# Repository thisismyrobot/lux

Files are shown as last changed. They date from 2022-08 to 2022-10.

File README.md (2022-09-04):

# Lux

A custom lux meter.

## Hardware

 - ESP-12F ESP8266 (bare)
 - BH1750 Ambient Light Sensor
 - Geekcreit 0.91 128x32 I2C OLED display
 - Resistors etc to support bare ESP8266
 - USB -> TTL (3.3v) adaptor for programming
 - Exact power supply TBD

## Enclosure

Laser-cut plates added to an purchased enclosure.

[Outlines DXF](https://github.com/thisismyrobot/lux/raw/main/hardware/2d_plates.dxf)

[Preview assembled](hardware/model.stl)

### Mock-up

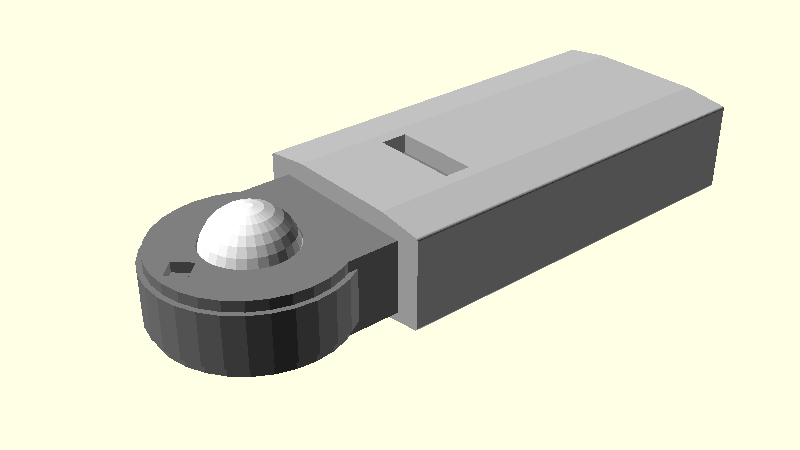
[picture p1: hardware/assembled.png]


### Plates

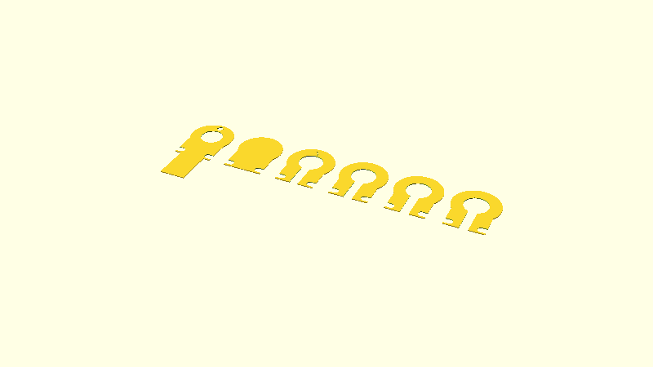
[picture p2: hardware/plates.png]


## Hat tips

https://www.instructables.com/ESP8266-Pro-Tips/

https://www.instructables.com/ESP-12F-ESP8266-Module-Minimal-Breadboard-for-Flas/

https://randomnerdtutorials.com/esp8266-nodemcu-bh1750-ambient-light-sensor/

https://learn.sparkfun.com/tutorials/esp8266-thing-hookup-guide/using-the-arduino-addon

https://randomnerdtutorials.com/esp8266-pinout-reference-gpios/

https://randomnerdtutorials.com/esp8266-0-96-inch-oled-display-with-arduino-ide/

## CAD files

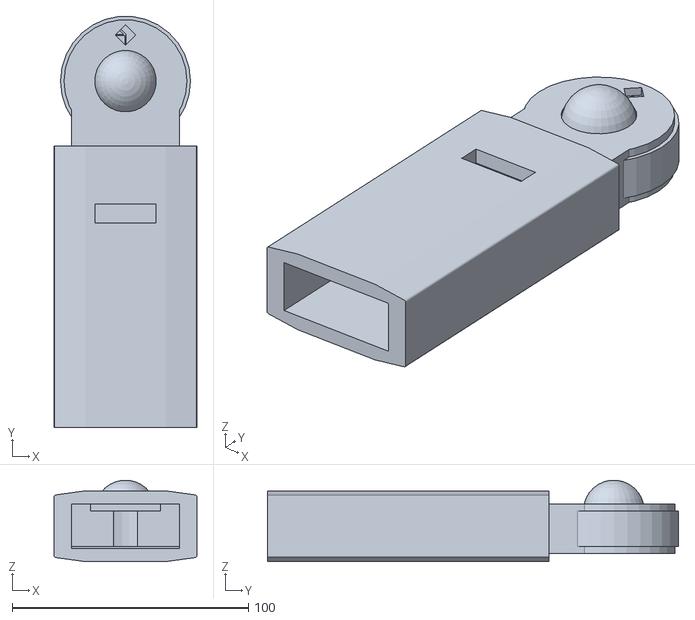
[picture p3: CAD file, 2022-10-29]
hardware/model.stl
60.4 x 173.8 x 34.4

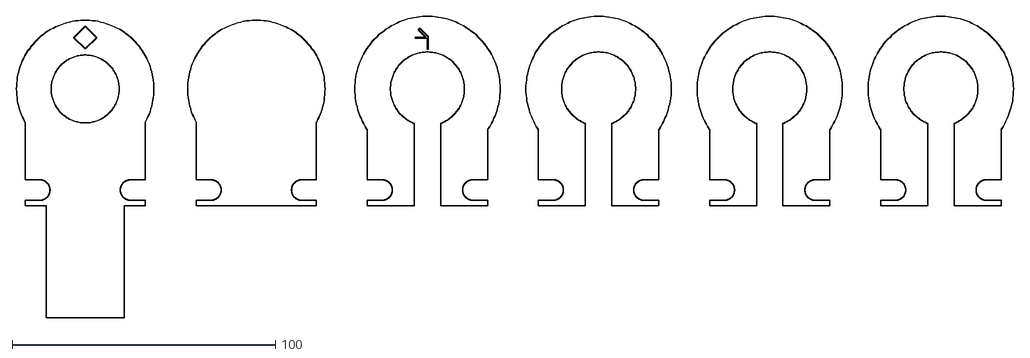
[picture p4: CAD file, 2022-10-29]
hardware/2d_plates.dxf
378.7 x 114.5

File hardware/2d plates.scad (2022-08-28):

$fn = 100;

case_width = 55;
case_radius = 5;

upper_dome_diam = 25.8;
lower_dome_diam = 28;
upper_dome_offset = 7;

upper_display_length = 23;
upper_display_width = 6;
upper_display_offset = 17;
lower_display_width = 12;
lower_display_length = 38.2;
lower_display_length_offset = 6.7;  // Pins end.

module plate() {
    offset(r=case_radius) square(case_width-case_radius*2, center=true);
}

module upper_plate() {
    difference() {
        plate();
        translate([0, upper_dome_offset, 0]) {
            circle(d=upper_dome_diam);
        }
        translate([0, -upper_display_offset, 0]) {
            square([upper_display_length, upper_display_width], center=true);
        }
    }
}

module lower_plate() {
    difference() {
        plate();
        translate([0, upper_dome_offset, 0]) {
            circle(d=lower_dome_diam);
        }
        cutout_offset = ((lower_display_length - upper_display_length) / 2) - lower_display_length_offset;
        echo(cutout_offset);

        translate([cutout_offset, -upper_display_offset, 0]) {
            square([lower_display_length, lower_display_width], center=true);
        }
    }
}

upper_plate();
translate([case_width+10, 0, 0]) lower_plate();

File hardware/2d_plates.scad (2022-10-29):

mode = "";
export = mode == "export";
$fn = export ? 150 : 30;

kerf = export ? 0.2 : 0;  // mm diameter of laser beam

plate_width = 55;
plate_thickness = 3;
plate_offset = plate_width / 2;
plate_step = 3;

upper_dome_diam = 26;
lower_dome_diam = 28.1;
dome_inner_width = 10;

box_width = 60.4;
box_length = 119;
box_height = 30;
box_hole_width = 45.5;
box_hole_height = 19;
box_inset_length = 16.9;
box_post_width = 8;
box_post_spacing = 34.5; // centres
box_post_inset = 10.9; // centres
box_ridge_width = 35;
box_ridge_roll = 1.5;
box_ridge_drop = 2.5;

middle_plates = floor(box_hole_height / plate_thickness) - 2;
add_fill_plate = (middle_plates + 2) * plate_thickness  != box_hole_height;

box_display_slot_from_end = 24.5;
box_display_slot_height = 8;
box_display_slot_length = 25.9;

module plate(step=0,tongue=0,trim=0) {
    tongue = trim > 0 ? -trim : tongue;
    difference() {
        union() {
            circle(d=plate_width-step+kerf);
            translate([-box_hole_width/2-kerf/2, -plate_width/2-box_inset_length+trim, 0]) square([box_hole_width+kerf, box_inset_length + plate_width/2 - trim]);
            translate([-box_hole_width/2+box_post_width-kerf/2, -plate_width/2-box_inset_length-tongue, 0]) square([box_hole_width-(box_post_width*2)+kerf, box_inset_length + plate_width/2 + tongue]);
        }
        hull() {
            translate([-box_post_spacing/2, -box_post_inset-plate_width/2, 0]) circle(d=box_post_width-kerf);
            translate([-box_post_spacing, -box_post_inset-plate_width/2, 0]) circle(d=box_post_width-kerf);
        }
        hull() {
            translate([box_post_spacing/2, -box_post_inset-plate_width/2, 0]) circle(d=box_post_width-kerf);
            translate([box_post_spacing, -box_post_inset-plate_width/2, 0]) circle(d=box_post_width-kerf);
        }
    }
}

module top_plate() {
    difference() {
        plate(plate_step, box_display_slot_from_end+box_display_slot_height+10);
        circle(d=upper_dome_diam-kerf);

        width = (plate_width-plate_step-upper_dome_diam) / 2;
        translate([0, upper_dome_diam/2 + width/2, 0]) rotate([0, 0, 45]) square((width/sqrt(2))/1.5, center=true);
    }
}

module middle_plate(logo=false) {
    difference() {
        plate();
        circle(d=lower_dome_diam);
        translate([-dome_inner_width/2, -box_inset_length-plate_width/2-1, 0]) {
            square([dome_inner_width, box_inset_length+plate_width/2]);
        }
        
        if (logo) {
            width = (plate_width-plate_step-upper_dome_diam) / 2;
            translate([0, upper_dome_diam/2 + width/2, 0]) {
                rotate([0, 0, 45]) translate([-width/40, 0, 0]) square([width/20, (width/sqrt(2))/2]);
                rotate([0, 0, 90]) translate([-width/80, 0, 0]) square([width/40, (width/sqrt(2))/2]);
                rotate([0, 0, 180]) translate([-width/60, -width/60, 0]) square([width/40, (width/sqrt(2))/2]);
            }
        }
    }
}

module bottom_plate(add_fill_plate) {
    plate(plate_step, 0, add_fill_plate ? box_inset_length : 0);
}

module dome() {
    color("white") difference() {
        sphere(d=upper_dome_diam);
        translate([0, 0, -plate_width/2]) cube([plate_width, plate_width, plate_width], center=true);
    }
}

module box() {
    translate([0, 0, -box_hole_height / 2]) difference() {
        // Master box
        union() {
            base_box_height = box_height-(box_ridge_drop*2);
            translate([-box_width/2, -box_length-plate_offset, -base_box_height/2]) cube([box_width, box_length, base_box_height]);

            // Top profile
            hull() {
                translate([0, -plate_offset, 0]) {
                    translate([-box_width/2+box_ridge_roll/2, 0, base_box_height/2]) rotate([90, 0, 0]) cylinder(d=box_ridge_roll, h=box_length);
                    translate([box_width/2-box_ridge_roll/2, 0, base_box_height/2]) rotate([90, 0, 0]) cylinder(d=box_ridge_roll, h=box_length);
                    translate([-box_ridge_width/2+box_ridge_roll/2, 0, base_box_height/2+box_ridge_drop-box_ridge_roll/2]) rotate([90, 0, 0]) cylinder(d=box_ridge_roll, h=box_length);
                    translate([box_ridge_width/2-box_ridge_roll/2, 0, base_box_height/2+box_ridge_drop-box_ridge_roll/2]) rotate([90, 0, 0]) cylinder(d=box_ridge_roll, h=box_length);
                }
            }   

            // Bottom profile
            hull() {
                translate([0, -plate_offset, 0]) {
                    translate([-box_width/2+box_ridge_roll/2, 0, -base_box_height/2]) rotate([90, 0, 0]) cylinder(d=box_ridge_roll, h=box_length);
                    translate([box_width/2-box_ridge_roll/2, 0, -base_box_height/2]) rotate([90, 0, 0]) cylinder(d=box_ridge_roll, h=box_length);
                    translate([-box_ridge_width/2+box_ridge_roll/2, 0, -base_box_height/2-box_ridge_drop+box_ridge_roll/2]) rotate([90, 0, 0]) cylinder(d=box_ridge_roll, h=box_length);
                    translate([box_ridge_width/2-box_ridge_roll/2, 0, -base_box_height/2-box_ridge_drop+box_ridge_roll/2]) rotate([90, 0, 0]) cylinder(d=box_ridge_roll, h=box_length);
                }
            }   
        }
        
        // End cutouts
        translate([-box_hole_width/2, -box_length-plate_offset-1, -box_hole_height/2]) cube([box_hole_width, box_length+2, box_hole_height]);

        // lcd cutout
        translate([0, -plate_offset-(box_display_slot_height/2)-box_display_slot_from_end, box_height/2]) {
            cube([box_display_slot_length, box_display_slot_height, box_height], center=true);
        }
    }
}

if (export) {
    top_plate();
    translate([plate_width+10, 0, 0]) bottom_plate();
    for (p = [0:middle_plates-1]) {
        translate([(p+2)*(plate_width+10), 0, 0]) middle_plate(p == 0);
    }
} else {
    translate([0, 0, -plate_thickness]) dome();
    color("silver") box();
    
    color("grey") translate([0, 0, -plate_thickness]) {
        linear_extrude(height=plate_thickness) top_plate();
        for (p = [1:middle_plates + (add_fill_plate ? 1 : 0)]) {
            translate([0, 0, -p*plate_thickness]) linear_extrude(height=plate_thickness) middle_plate(p == 1);
        }
        translate([0, 0, -plate_thickness*(middle_plates+1+(add_fill_plate ? 1 : 0))]) linear_extrude(height=plate_thickness) bottom_plate(add_fill_plate);
    }
}

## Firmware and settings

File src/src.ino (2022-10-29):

/* 
 *  Add board manager URL: http://arduino.esp8266.com/stable/package_esp8266com_index.json
 *  Add board via board manager: esp8266 v3.0.2
 *  Select this ESP8266 board: Generic ESP8266 Module
 *  Install Libraries:
 *      - BH1750 v1.3.0
 *      - Adafruit SSD1306 v2.5.7
*/
#include <ESP8266WiFi.h>
#include <Wire.h>
#include <BH1750.h>
#include <Adafruit_SSD1306.h>

#define SDA_PIN 4  // GPIO4/Pin 19/D2
#define SCL_PIN 5  // GPIO5/Pin 20/D1

#define SCREEN_WIDTH 128
#define SCREEN_HEIGHT 32
#define OLED_RESET -1
#define SCREEN_ADDRESS 0x3C

BH1750 lightMeter;
Adafruit_SSD1306 display(SCREEN_WIDTH, SCREEN_HEIGHT, &Wire, OLED_RESET);

void setup() {
    WiFi.mode(WIFI_OFF);
    WiFi.forceSleepBegin();
    delay(1);

    pinMode(LED_BUILTIN, OUTPUT);

    Wire.begin(SDA_PIN, SCL_PIN);
    if(!display.begin(SSD1306_SWITCHCAPVCC, SCREEN_ADDRESS)) {
        Serial.println(F("SSD1306 allocation failed"));
        for(;;); // Don't proceed, loop forever
    }
    display.setTextSize(4);
    display.setTextColor(SSD1306_WHITE);
    
    lightMeter.begin(BH1750::CONTINUOUS_HIGH_RES_MODE_2);
}

void loop() {
    digitalWrite(LED_BUILTIN, LOW);
    delay(100);

    int lux = lightMeter.readLightLevel();
    drawLux(lux);
    
    digitalWrite(LED_BUILTIN, HIGH);
    delay(100);
}

void drawLux(int lux) {
    display.clearDisplay();
    display.setCursor(0, 0);

    int leftPad = 5 - floor(log10(lux) + 1);
    for(int i=0; i<leftPad; i++) {
        display.print(" ");
    }
    
    display.print(lux);
    display.display();
}

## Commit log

2022-08-19 Fixed serial logging, wasn't working in setup
    [src.ino]
2022-08-19 Working lux reading from the sensor
2022-08-28 Trialling some plates for laser cutting
    [2d plates.dxf, 2d plates.scad]
2022-08-28 DXF exporting with flag
    [2d_plates.dxf, 2d_plates.scad]
2022-08-31 Redesigned to be part of existing enclosure
    [2d_plates.dxf, 2d_plates.scad]
2022-08-31 Exporting STL to show the concept better
    [2d_plates.scad, model.stl]
2022-08-31 Added stack of middle plates
    [2d_plates.dxf, 2d_plates.scad, model.stl]
2022-08-31 Added step option for plates
    [2d_plates.dxf, 2d_plates.scad, model.stl]
2022-09-04 Added mounting pate for LCD, slot for LCD
    [2d_plates.dxf, 2d_plates.scad, model.stl]
2022-09-04 Improved preview of box to help with design
    [2d_plates.scad, model.stl]
2022-09-11 Tweaked maths for plate count
    [2d_plates.scad, model.stl]
2022-09-11 Added a fill plate if the plates don't add up to the gap height
    [2d_plates.dxf, 2d_plates.scad, model.stl]
2022-09-11 Bugfixes to last
    [2d_plates.dxf, 2d_plates.scad, model.stl]
2022-09-11 Added laser kerf allowance when exporting
    [2d_plates.dxf, 2d_plates.scad, model.stl]
2022-09-11 Embedded logo representation
    [2d_plates.dxf, 2d_plates.scad, model.stl]
2022-10-29 Actual v1 settings that worked with the real perspex
    [2d_plates.dxf, 2d_plates.scad, model.stl]
